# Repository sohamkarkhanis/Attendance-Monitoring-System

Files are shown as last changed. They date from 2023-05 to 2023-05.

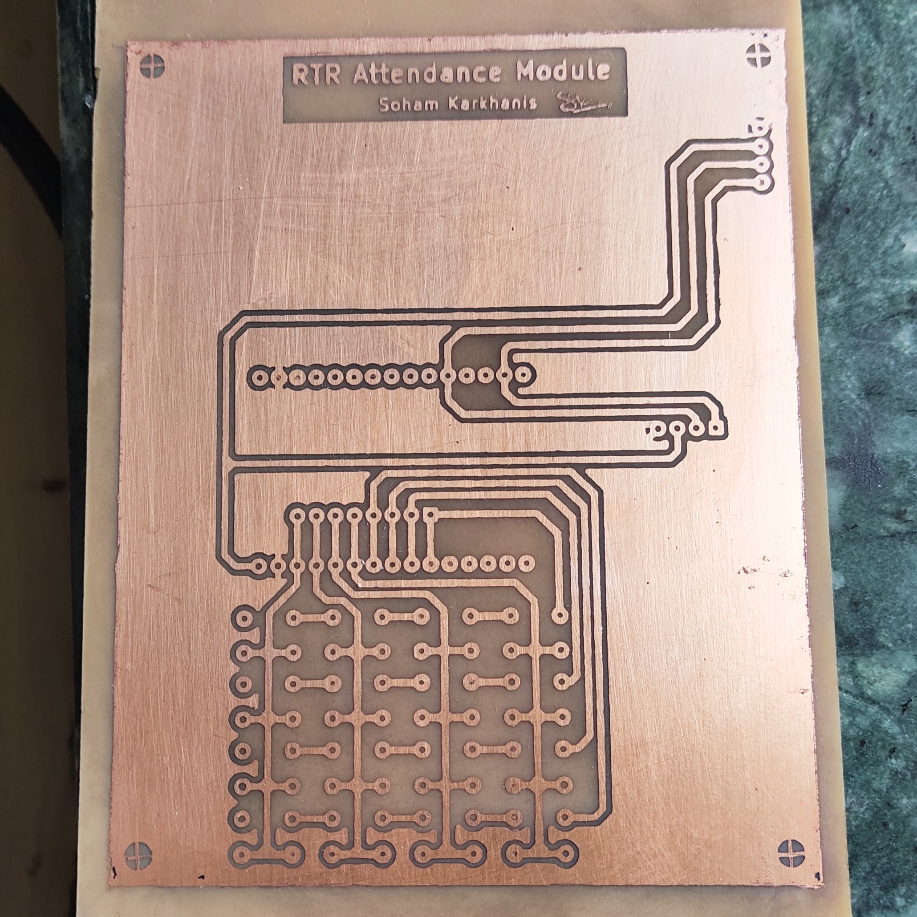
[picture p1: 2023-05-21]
PCB Design/Post Production Images/Manufactured PCB.jpg

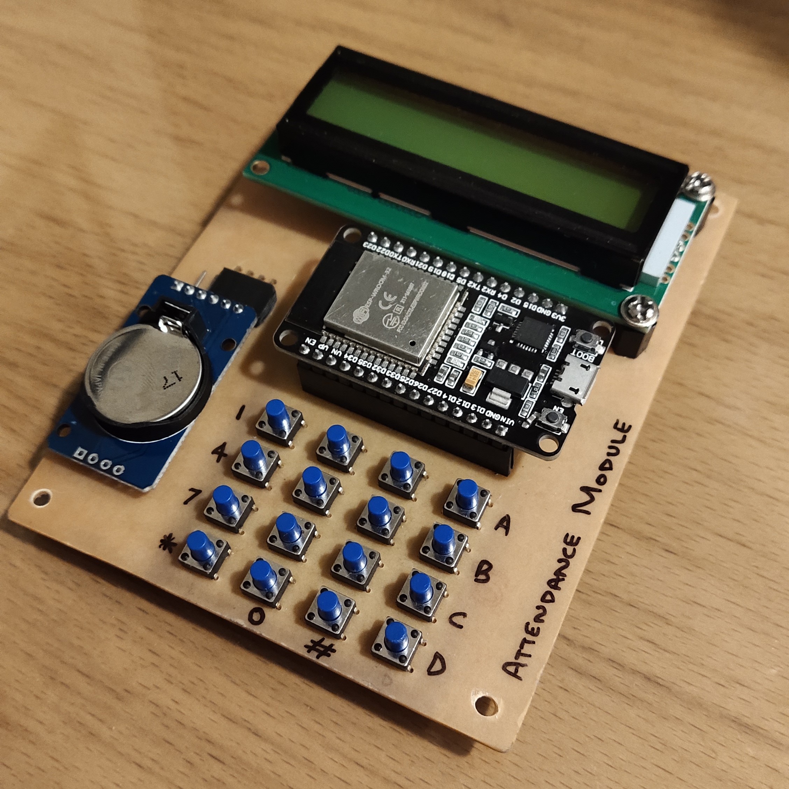
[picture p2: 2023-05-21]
PCB Design/Post Production Images/PCB Assembled.jpg

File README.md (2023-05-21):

# Attendance Monitoring System

This repository contains the code and documentation for an Attendance Monitoring System based on the ESP32 with a DS3231 RTC and the Hitachi HD44780, 16x2 character LCD with a PCF8574 I2C backpack. The system allows users to record attendance using a 4x4 matrix keypad through which Roll Numbers are entered and registered.

This project is designed to automate the process of attendance taking, saving time and reducing errors. With a focus on simplicity and cost-efficiency, it offers a dependable solution for monitoring the attendance in small institutions where advanced methods such as RFID, biometrics, etc… are not required.

Refer to the block diagram, PCB layout, schematic, and the code within the repository for detailed explanations and understanding of the project's functionality and hardware connections.

---

Author: Soham Karkhanis

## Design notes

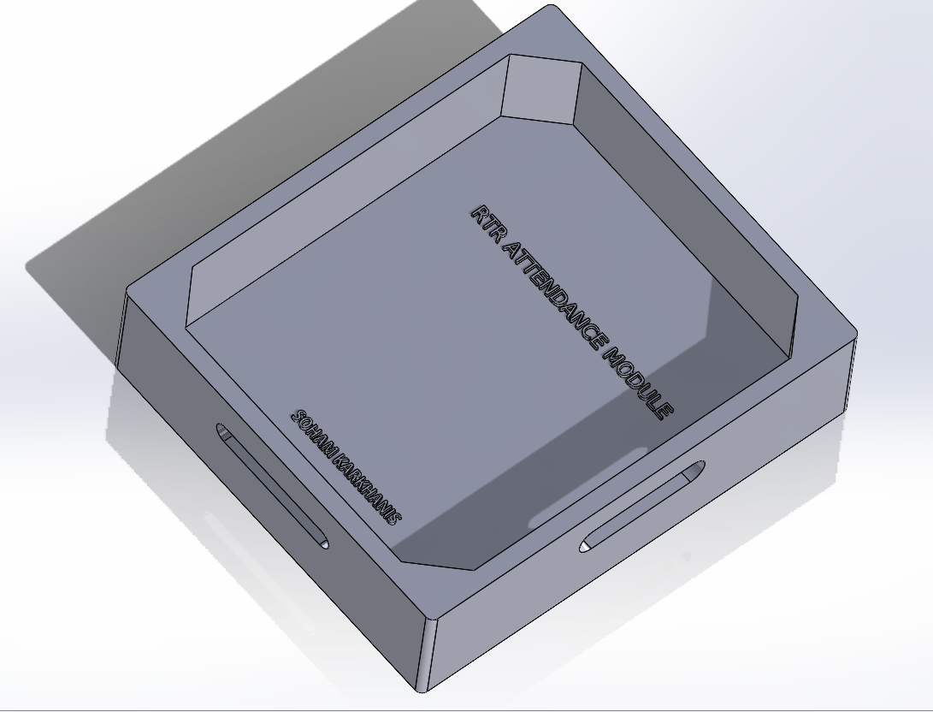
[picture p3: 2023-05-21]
Enclosure Design/Images/Box.png

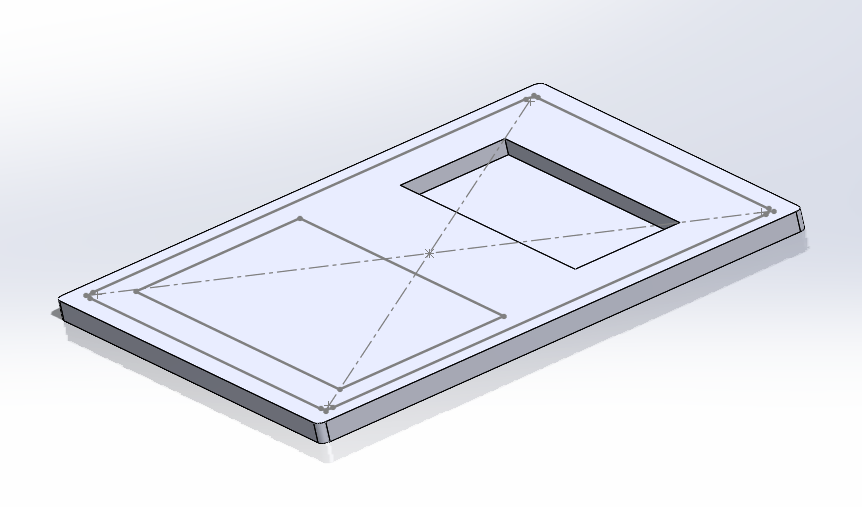
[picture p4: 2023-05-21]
Enclosure Design/Images/Lid.png

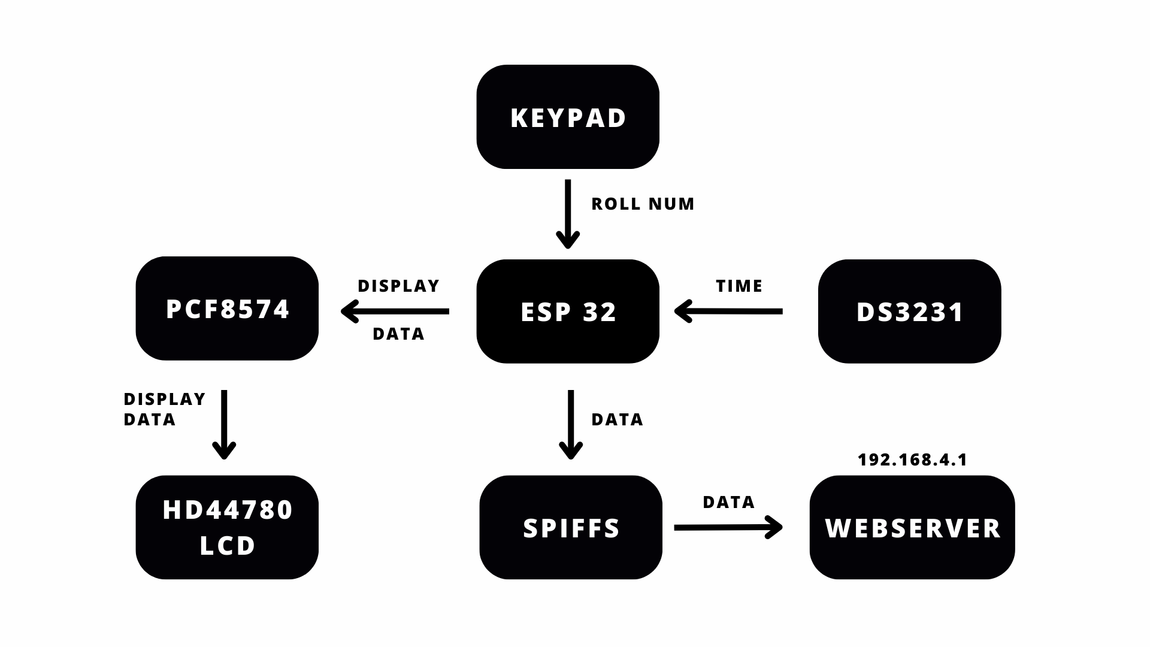
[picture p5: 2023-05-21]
Block Diagram.png

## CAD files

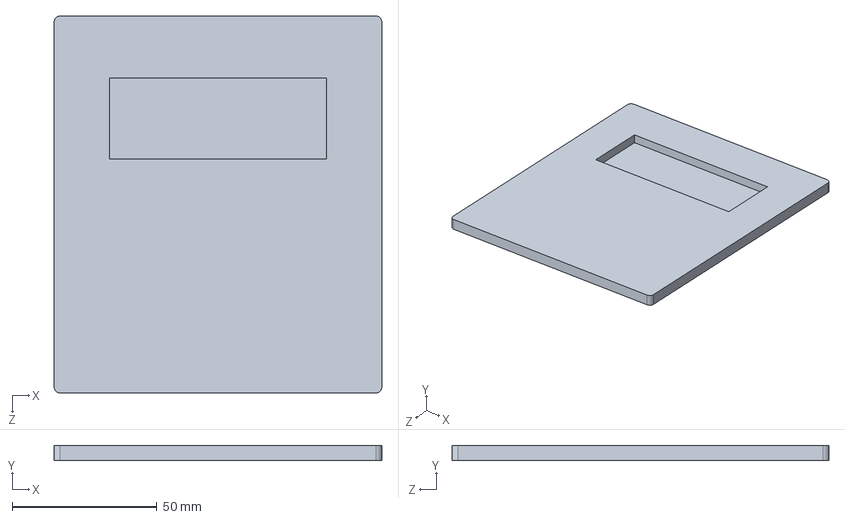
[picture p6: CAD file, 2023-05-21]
Enclosure Design/Lid.SLDPRT
113.0 x 5.00 x 130.0 mm

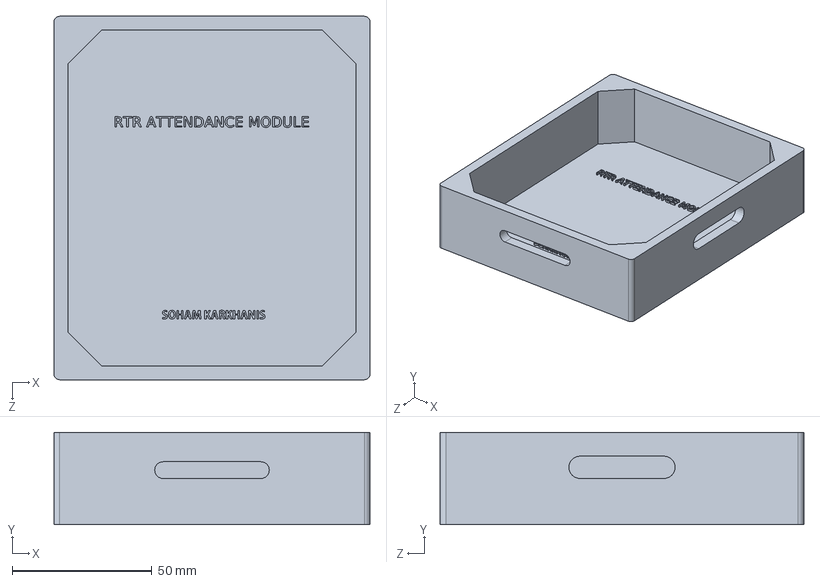
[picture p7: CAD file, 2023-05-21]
Enclosure Design/Box.SLDPRT
113.0 x 33.0 x 130.0 mm

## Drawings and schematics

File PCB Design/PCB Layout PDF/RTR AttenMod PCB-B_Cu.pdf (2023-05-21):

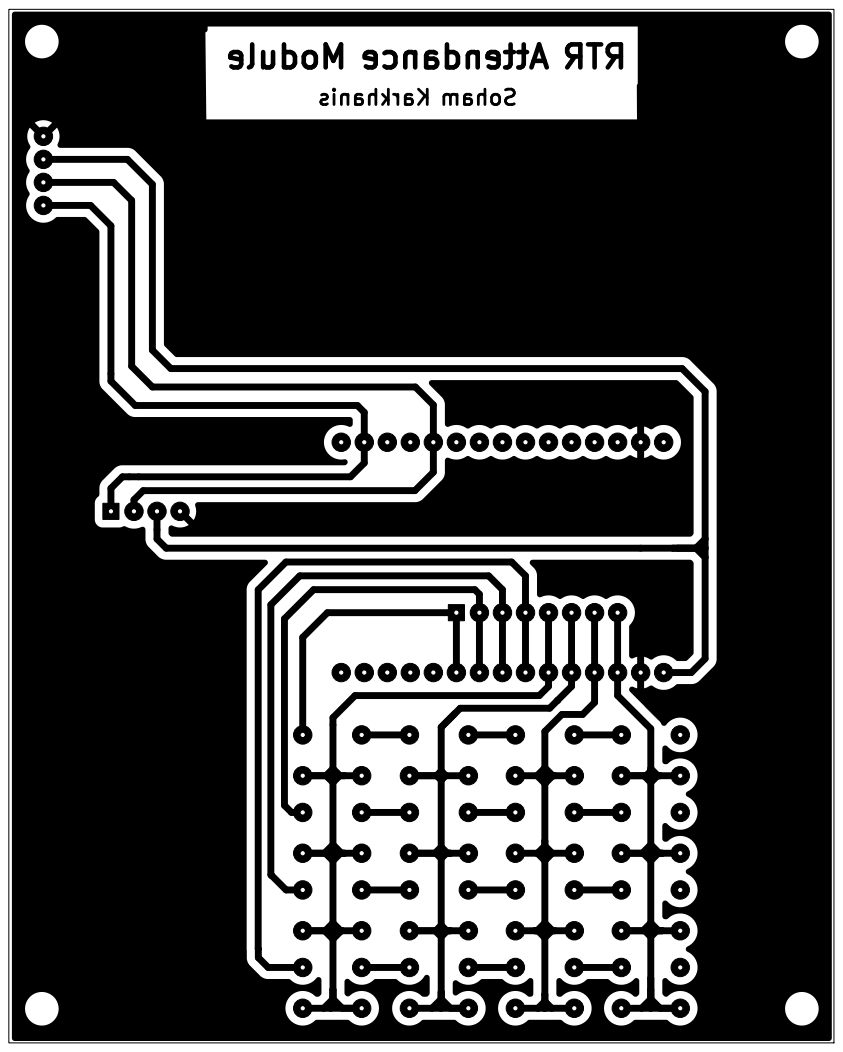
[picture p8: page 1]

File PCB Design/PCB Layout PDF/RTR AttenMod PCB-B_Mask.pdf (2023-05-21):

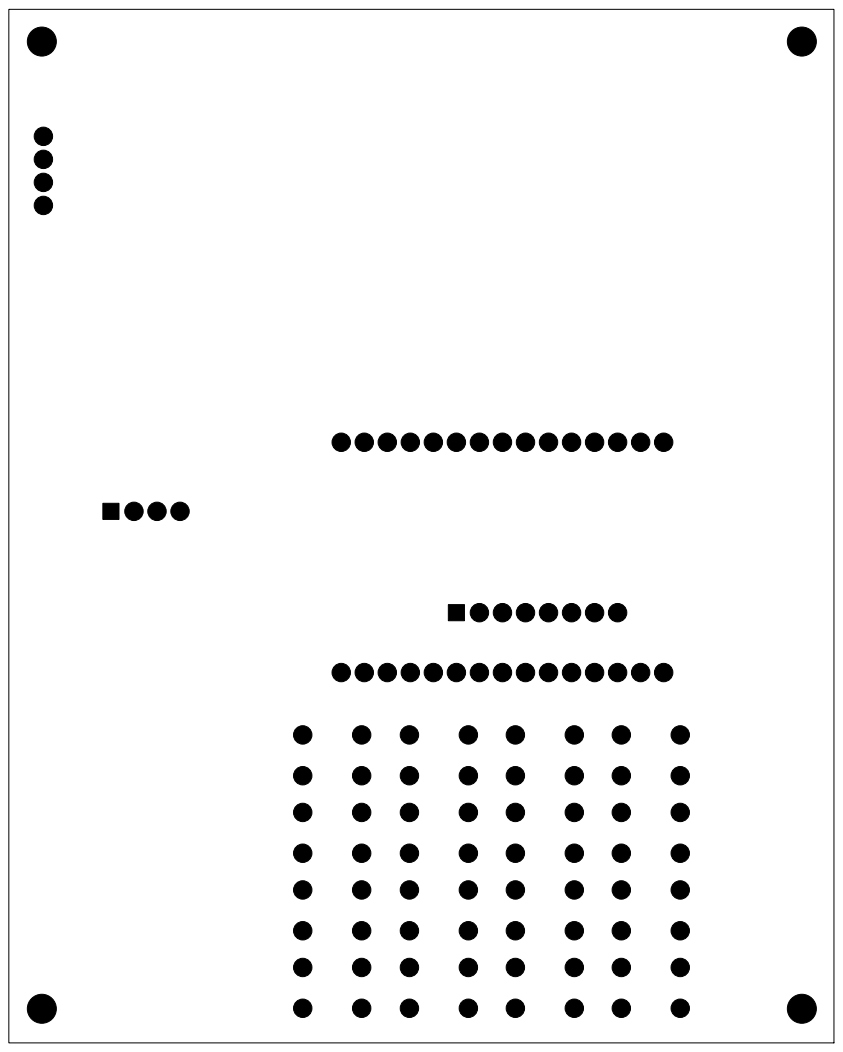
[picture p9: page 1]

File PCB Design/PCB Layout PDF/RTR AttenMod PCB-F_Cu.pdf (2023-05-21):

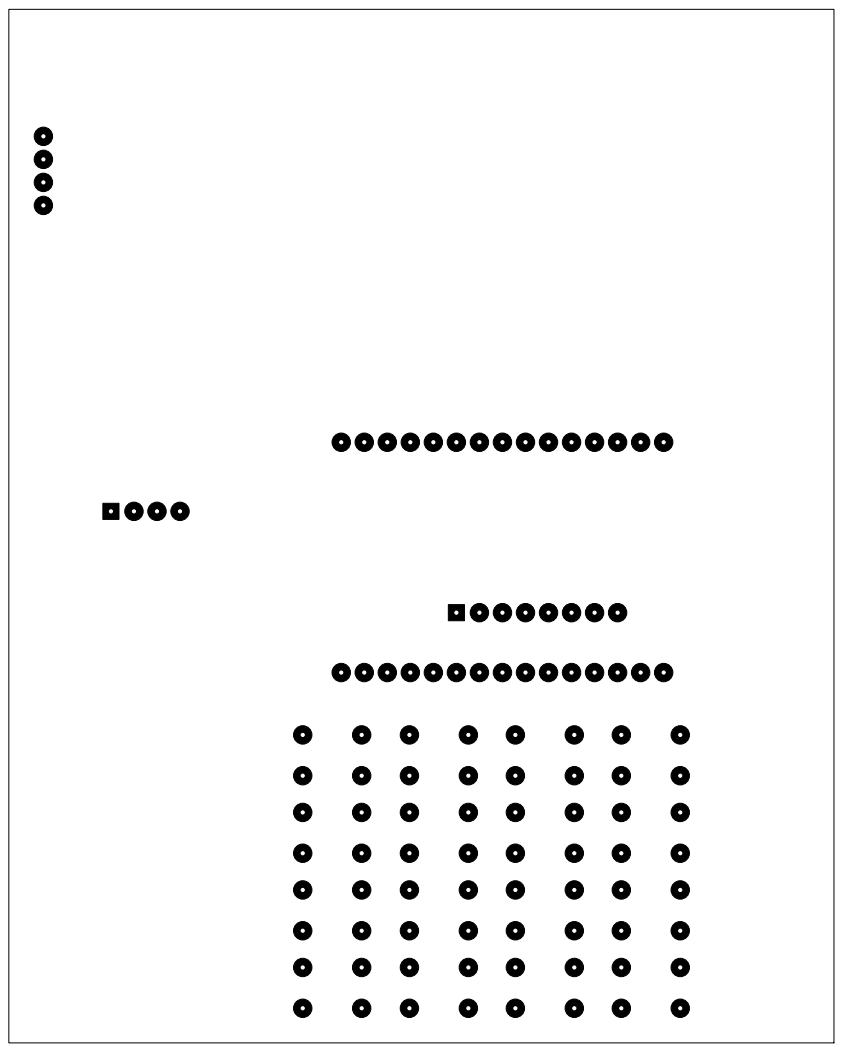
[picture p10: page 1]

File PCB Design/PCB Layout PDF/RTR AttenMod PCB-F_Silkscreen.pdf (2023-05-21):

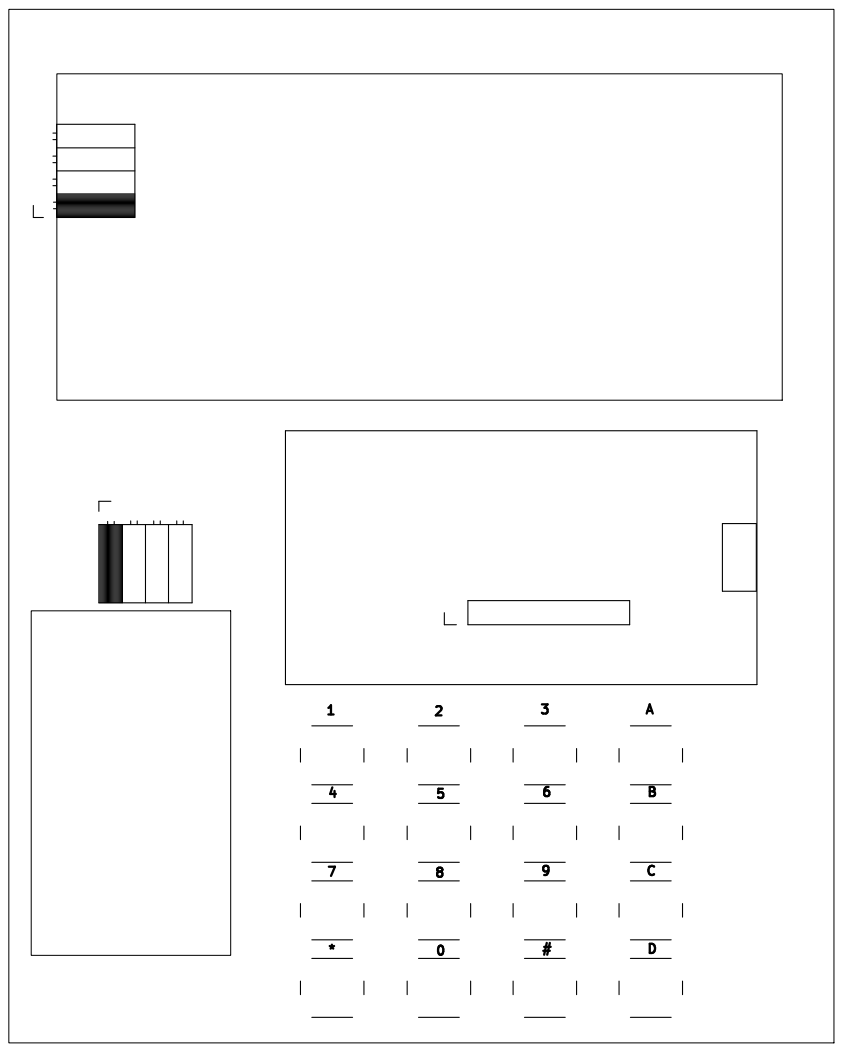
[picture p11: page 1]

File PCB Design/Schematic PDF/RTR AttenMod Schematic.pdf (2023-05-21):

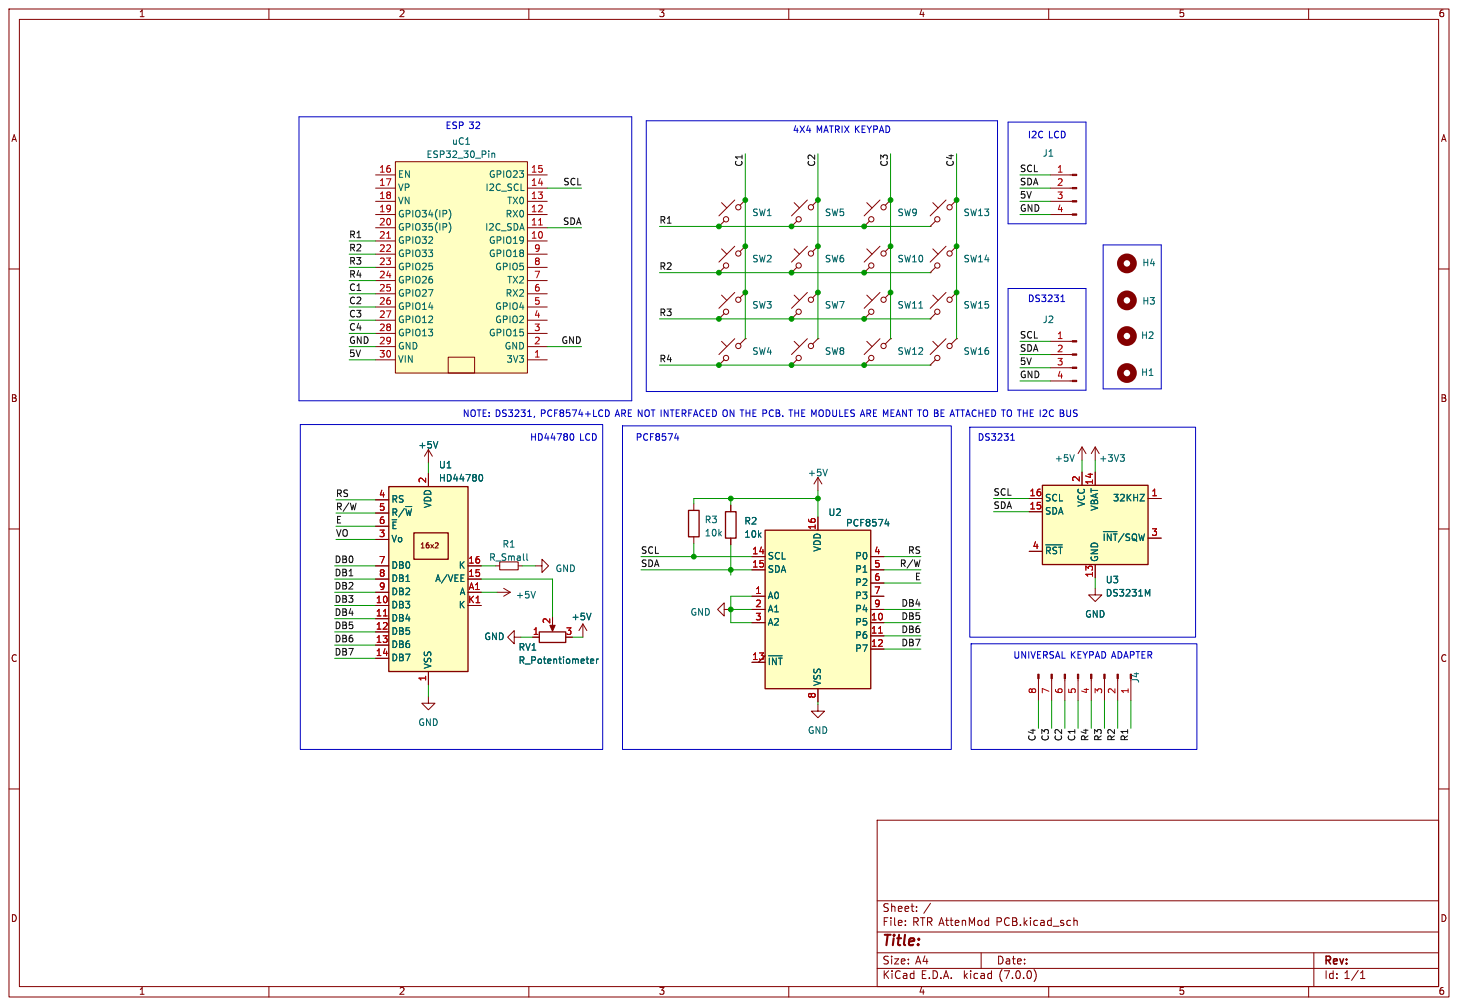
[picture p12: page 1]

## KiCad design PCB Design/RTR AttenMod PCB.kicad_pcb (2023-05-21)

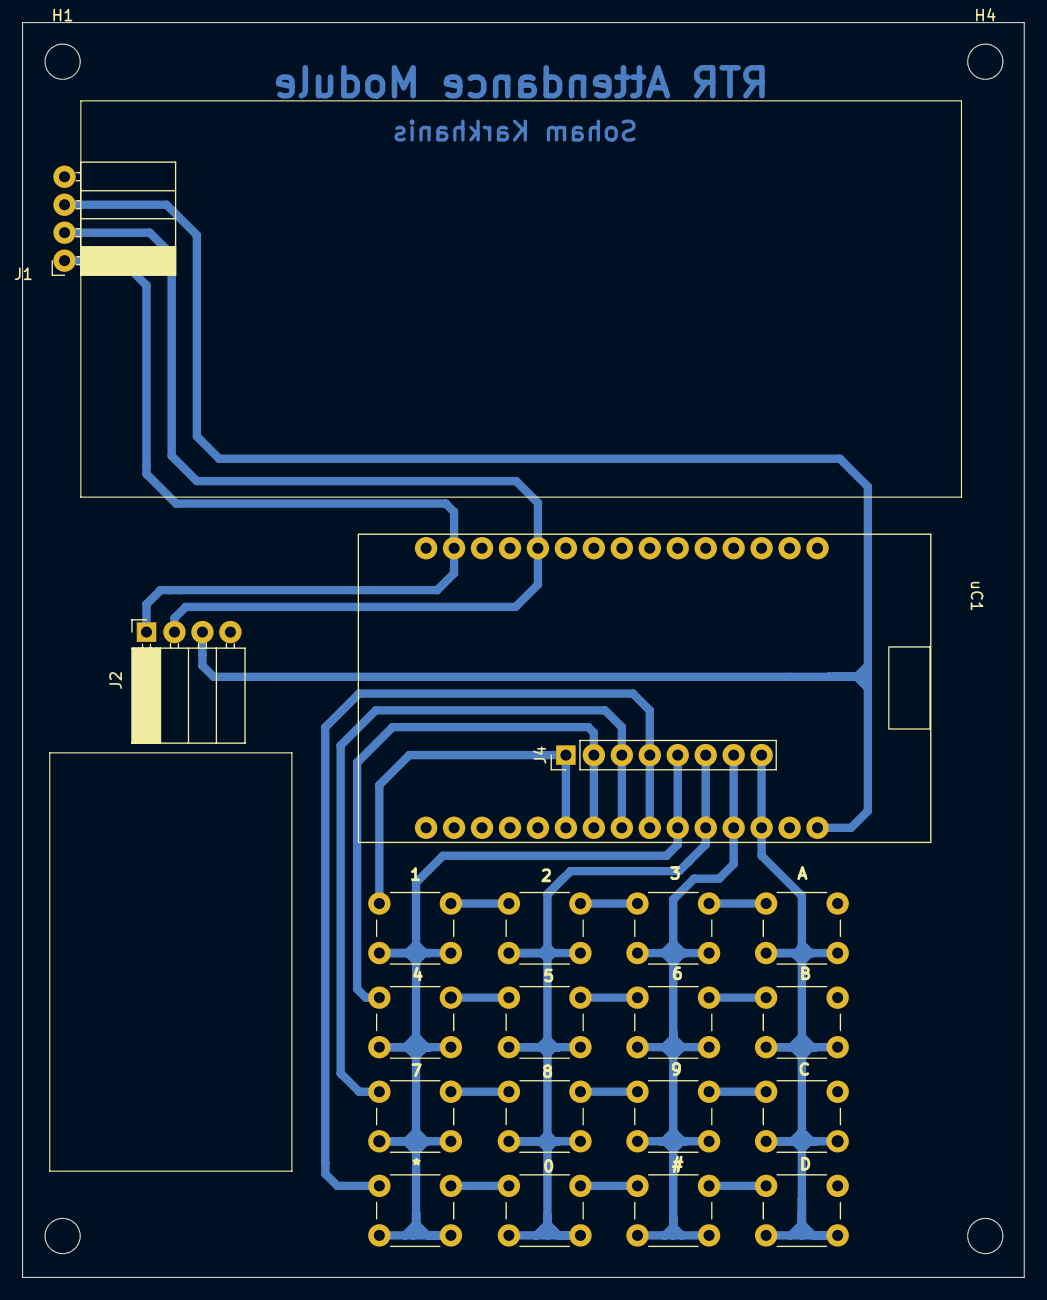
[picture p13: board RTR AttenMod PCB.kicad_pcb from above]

Board: 2 copper layers, 91.0 x 114.0 mm, 24 parts (0 on the bottom side), 12 nets.

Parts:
H1, H2, H3, H4: MountingHole; MountingHole_3.2mm_M3
J1, J2: Conn_01x04_Male; PinSocket_1x04_P2.54mm_Horizontal
J4: Conn_01x08_Pin; PinHeader_1x08_P2.54mm_Vertical
SW1, SW2, SW3, SW4, SW5, SW6, SW7, SW8, SW9, SW10, SW11, SW12, SW13, SW14, SW15, SW16: SW_Push_45deg; SW_PUSH_6mm
uC1: ESP32_30_Pin

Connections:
/5V: J1.3, J2.3, uC1.30 (VIN)
/C1: J4.5, SW1.2, SW2.2, SW3.2, SW4.2, uC1.25 (GPIO27)
/C2: J4.6, SW5.2, SW6.2, SW7.2, SW8.2, uC1.26 (GPIO14)
/C3: J4.7, SW9.2, SW10.2, SW11.2, SW12.2, uC1.27 (GPIO12)
/C4: J4.8, SW13.2, SW14.2, SW15.2, SW16.2, uC1.28 (GPIO13)
/R1: J4.1, SW1.1, SW5.1, SW9.1, SW13.1, uC1.21 (GPIO32)
/R2: J4.2, SW2.1, SW6.1, SW10.1, SW14.1, uC1.22 (GPIO33)
/R3: J4.3, SW3.1, SW7.1, SW11.1, SW15.1, uC1.23 (GPIO25)
/R4: J4.4, SW4.1, SW8.1, SW12.1, SW16.1, uC1.24 (GPIO26)
/SCL: J1.1, J2.1, uC1.14 (I2C SCL)
/SDA: J1.2, J2.2, uC1.11 (I2C SDA)
GND: J1.4, J2.4, uC1.2 (GND), uC1.29 (GND)

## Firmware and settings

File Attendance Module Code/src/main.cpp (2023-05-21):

/*
**************************************************************************************************
                                        Author: Soham Karkhanis
**************************************************************************************************

To better explain the code, here's a flowchart giving a brief overview of the attendance registering process,
skipping some of the finer details:

Start at home screen, automatically connect to Wifi if availiable
|
Read key from keypad
|
Is key '*'?
|
|--- Yes
|   |
|   Prompt for RollNumber input
|   |
|   Is RollNumber valid and mapped to a user?
|   |
|   |--- Yes
|   |   |
|   |   Confirm attendance
|   |   |
|   |   Is attendance confirmed?
|   |   |
|   |   |--- Yes
|   |   |   |
|   |   |   Display "Welcome" message
|   |   |   |
|   |   |   Mark attendance
|   |   |
|   |   |--- No
|   |   |   |
|   |   |   Back to homescreen
|   |
|   |--- No
|   |   |
|   |   Display error message: "User Not Found"
|   |
|   Clear LCD display
|
|--- No
|   |
|   Is key 'D'?
|   |
|   |--- Yes
|   |   |
|   |   Prompt for RollNumber input
|   |   |
|   |   Is RollNumber valid and mapped to a user?
|   |   |
|   |   |--- Yes
|   |   |   |
|   |   |   Confirm departure
|   |   |   |
|   |   |   Is departure confirmed?
|   |   |   |
|   |   |   |--- Yes
|   |   |   |   |
|   |   |   |   Display "Goodbye" message
|   |   |   |   |
|   |   |   |   Mark departure
|   |   |   |
|   |   |   |--- No
|   |   |   |   |
|   |   |   |   Back to homescreen
|   |   |
|   |   |--- No
|   |   |   |
|   |   |   Display error message: "User Not Found"
|   |
|   |
|   |
|   |--- No
|   |   |
|   |   |   Is key 'B'?
|   |   |   |
|   |   |   |--- Yes
|   |   |   |    |
|   |   |   |    Display IP Address
|   |   |   |--- No
|   |   |   |    |
|   |   |   |    Wait for keypress on homescreen

End

*/

#include "FS.h"
#include "SPIFFS.h"
#include "data.h"
#include <Arduino.h>
#include <ESPAsyncWebServer.h>
#include <Keypad.h>
#include <LiquidCrystal_I2C.h>
#include <WiFi.h>
#include <Wire.h>

// #define INIT_RTC

//----------------------------------------RTC---------------------------------------
#define DS3231_READ 0xD1
#define DS3231_WRITE 0xD0
#define DS3231_ADDR 0x68
#define DS3231_SECONDS 0x00
#define DS3231_MINUTES 0x01
#define DS3231_HOURS 0x02
#define DS3231_DAY 0x03
#define DS3231_DATE 0x04
#define DS3231_CEN_MONTH 0x05

#define DS3231_DEC_YEAR 0x06
#define DS3231_TEMP_MSB 0x11
#define DS3231_TEMP_LSB 0x12
const byte ROWS = 4;
const byte COLS = 4;
char keys[ROWS][COLS] = {
    { '1', '2', '3', 'A' },
    { '4', '5', '6', 'B' },
    { '7', '8', '9', 'C' },
    { '*', '0', '#', 'D' }
};

byte rowPins[ROWS] = { 32, 33, 25, 26 };        // connect to the row pinouts of the kpd
byte colPins[COLS] = { 27, 14, 12, 13 };        // connect to the column pinouts of the kpd
const char *ssid = "AttendanceModule";
const char *password = "password";

// Objects
AsyncWebServer server(80);
LiquidCrystal_I2C lcd(0x27, 16, 2);
byte klock[] = { 0x00, 0x0E, 0x15, 0x15, 0x1D, 0x11, 0x11, 0x0E };
Keypad keypad = Keypad(makeKeymap(keys), rowPins, colPins, ROWS, COLS);

char key;
uint8_t value = 0;
char const *wdays[] = { "Sun", "Mon", "Tue", "Wed", "Thu", "Fri", "Sat" };

uint8_t hours, minutes, seconds, datee, month, yearr, day;

String dataMessage;
float temp;
ulong timer_A;

// Function Prototypes
void getDate();
void getTime();
uint8_t toBcd(uint8_t num);
uint8_t fromBcd(uint8_t bcd);
uint8_t readRegister(uint8_t reg);
void writeRegister(uint8_t reg, uint8_t data);
void listDir(fs::FS &fs, const char *dirname, uint8_t levels);
void readFile(fs::FS &fs, const char *path);
void writeFile(fs::FS &fs, const char *path, const char *message);
void appendFile(fs::FS &fs, const char *path, const char *message);
void renameFile(fs::FS &fs, const char *path1, const char *path2);
void deleteFile(fs::FS &fs, const char *path);
void markAttendance(int rollNum, String name);
void markDeparture(int rollNum, String name);

// --------------------------------------------------------------------------------------- SETUP ----------
void setup() {
    Serial.begin(115200);
    Wire.begin();
    Serial.print("Setting AP (Access Point)…");
    WiFi.softAP(ssid, password);

    IPAddress IP = WiFi.softAPIP();
    Serial.print("AP IP address: ");
    Serial.println(IP);

    server.on("/", HTTP_GET, [](AsyncWebServerRequest *request) { request->send(SPIFFS, "/index.html", "text/html"); });
    server.on("/csv", HTTP_GET, [](AsyncWebServerRequest *request) { request->send(SPIFFS, "/RTR_Attendance.csv", "text/csv"); });
    // server.on("/plain", HTTP_GET, [](AsyncWebServerRequest *request) { request->send(200, "text/plain", "You have reached the WebServer for the RTR Attendance Module designed by Soham Karkhanis. \n Append /csv to the URL to get the csv file containing the attendance record"); });
    server.on("/test", HTTP_GET, [](AsyncWebServerRequest *request) { request->send_P(200, "text/plain", "Hello World"); });
    server.begin();

    if (!SPIFFS.begin(true)) {
        Serial.println("An Error has occurred while mounting SPIFFS");
        return;
    }

    File file = SPIFFS.open("/test.txt");
    if (!file) {
        Serial.println("Failed to open file for reading");
        return;
    }

    Serial.println("File Content:");
    while (file.available()) {
        Serial.print((char)file.read());
    }
    file.close();

#ifdef INIT_RTC
    writeRegister(DS3231_HOURS, 16);
    writeRegister(DS3231_MINUTES, 32);
    writeRegister(DS3231_SECONDS, 0);

    writeRegister(DS3231_DAY, 5);
    writeRegister(DS3231_DATE, 12);
    writeRegister(DS3231_CEN_MONTH, 5);
    writeRegister(DS3231_DEC_YEAR, 23);
#endif

    lcd.init();
    lcd.backlight();
    lcd.print("Initializing...");
    // lcd.createChar(0, klock);
    getDate();
    getTime();
    delay(800);
    lcd.clear();
    lcd.setCursor(0, 0);
    lcd.print(wdays[day]);
    lcd.print(" " + (String)datee + "/" + (String)month + "/" + (String)yearr);
    lcd.setCursor(0, 1);
    lcd.print("* Arr | D Depart");
    lcd.setCursor(0, 1);
    Serial.println(" ");
}
// --------------------------------------------------------------------------------------- SETUP END ----------
// ------------------------------------------------------------------------------------------------------------------------------ LOOP  ----------
void loop() {
    key = keypad.getKey();

    // --------------------------------------------------------------------------------------- IF KEY * DO ARRIVE STUFF  ----------
    if (key == '*') {
        lcd.clear();
        lcd.print("Enter Your RNum");
        lcd.setCursor(0, 1);
        key = ' ';
        while (key == NULL || key == ' ' || key == '*' || key == 'B' || key == 'D' || key == 'A') {
            key = keypad.getKey();
            if (key == 'B' || key == 'D' || key == 'A') {
                lcd.setCursor(0, 0);
                lcd.print("Enter Valid Num:");
            }
        }
        // ----------------------------------------------------------------------- C TO RETURN TO PREV MENU  ----------
        if (key == 'C') {
            getDate();
            getTime();
            lcd.clear();
            lcd.print(wdays[day]);
            lcd.print(" " + (String)datee + "/" + (String)month + "/" + (String)yearr);
            lcd.setCursor(0, 1);
            lcd.print("* Arr | D Depart");
            lcd.setCursor(0, 0);
            return;
        }

        lcd.setCursor(0, 1);
        lcd.print(key);
        value = (int)key - 48;
        value = value * 10;
        key = ' ';

        while (key == NULL || key == ' ' || key == '*' || key == 'B' || key == 'D' || key == 'A') {
            key = keypad.getKey();
            if (key == 'B' || key == 'D' || key == 'A') {
                lcd.setCursor(0, 0);
                lcd.print("Enter Valid Num:");
            }
        }

        if (key == 'C') {
            getDate();
            getTime();
            lcd.clear();
            lcd.print(wdays[day]);
            lcd.print(" " + (String)datee + "/" + (String)month + "/" + (String)yearr);
            lcd.setCursor(0, 0);
            lcd.print("* Arr | D Depart");
            lcd.setCursor(0, 1);

            return;
        }

        lcd.print(key);
        value = value + ((int)key - 48);
        lcd.setCursor(0, 0);
        lcd.print("# Confirm C Abrt");
        //  Serial.println("Press # to mark attendance or Press C to cancel");
        while (key != 'C' && key != '#')
            key = keypad.getKey();
        if (key == 'C') {
            getDate();
            getTime();
            lcd.clear();
            lcd.print(wdays[day]);
            lcd.print(" " + (String)datee + "/" + (String)month + "/" + (String)yearr);
            lcd.setCursor(0, 1);
            lcd.print("* Arr | D Depart");
            value = 0;
            // ----------------------------------------------------------------------- IF #, MARK ATTENDANCE  ----------
        } else if (key == '#') {
            getDate();
            getTime();
            if (student_data.find(value) == student_data.end()) {
                lcd.clear();
                lcd.setCursor(0, 0);
                lcd.print("Error");
                lcd.setCursor(0, 1);
                lcd.print("User Not Found");
                delay(2000);
            } else {
                auto student = student_data.find(value);
                markAttendance(value, student->second);
                lcd.clear();
                lcd.setCursor(0, 0);
                lcd.print("Welcome Back");
                lcd.setCursor(0, 1);
                lcd.print(student->second);
                delay(2000);
            }
            getDate();
            getTime();
            lcd.clear();
            lcd.print(wdays[day]);
            lcd.print(" " + (String)datee + "/" + (String)month + "/" + (String)yearr);
            lcd.setCursor(0, 1);
            lcd.print("* Arr | D Depart");
            lcd.setCursor(0, 0);
        }
        key = ' ';
    }
    // --------------------------------------------------------------------------------------- IF KEY D DO DEPART STUFF  ----------
    else if (key == 'D') {
        lcd.clear();
        lcd.print("Enter Your RNum");
        lcd.setCursor(0, 1);
        key = ' ';
        while (key == NULL || key == ' ' || key == '*' || key == 'B' || key == 'A' || key == 'D') {
            key = keypad.getKey();
            if (key == 'B' || key == '*' || key == 'A' || key == 'D') {
                lcd.setCursor(0, 0);
                lcd.print("Enter Valid Num:");
            }
        }
        if (key == 'C') {
            getDate();
            getTime();
            lcd.clear();
            lcd.print(wdays[day]);
            lcd.print(" " + (String)datee + "/" + (String)month + "/" + (String)yearr);
            lcd.setCursor(0, 1);
            lcd.print("* Arr | D Depart");
            lcd.setCursor(0, 0);
            value = 0;
            return;
        }
        lcd.setCursor(0, 1);
        lcd.print(key);
        value = (int)key - 48;
        value = value * 10;
        key = ' ';
        while (key == NULL || key == ' ' || key == '*' || key == 'B' || key == '*' || key == 'A') {
            key = keypad.getKey();
            if (key == 'B' || key == '*' || key == 'A') {
                lcd.setCursor(0, 0);
                lcd.print("Enter Valid Num:");
            }
        }
        if (key == 'C') {
            getDate();
            getTime();
            lcd.clear();
            lcd.print(wdays[day]);
            lcd.print(" " + (String)datee + "/" + (String)month + "/" + (String)yearr);
            lcd.setCursor(0, 1);
            lcd.print("* Arr | D Depart");
            lcd.setCursor(0, 0);
            value = 0;
            return;
        }
        lcd.print(key);
        value = value + ((int)key - 48);
        lcd.setCursor(0, 0);
        lcd.print("# Confirm C Abrt");
        // Serial.println("Press # to mark attendance or Press C to cancel");
        while (key != 'C' && key != '#')
            key = keypad.getKey();
        if (key == 'C') {
            getDate();
            getTime();
            lcd.clear();
            lcd.print(wdays[day]);
            lcd.print(" " + (String)datee + "/" + (String)month + "/" + (String)yearr);
            lcd.setCursor(0, 1);
            lcd.print("* Arr | D Depart");
            lcd.setCursor(0, 0);
            value = 0;
        } else if (key == '#') {
            getDate();
            getTime();
            if (student_data.find(value) == student_data.end()) {
                lcd.clear();
                lcd.setCursor(0, 0);
                lcd.print("Error");
                lcd.setCursor(0, 1);
                lcd.print("User Not Found");
                delay(2000);
            } else {
                auto student = student_data.find(value);
                markDeparture(value, student->second);
                lcd.clear();
                lcd.setCursor(0, 0);
                lcd.print("See You Soon");
                lcd.setCursor(0, 1);
                lcd.print(student->second);
                delay(2000);
            }

            getDate();
            getTime();
            lcd.clear();
            lcd.print(wdays[day]);
            lcd.print(" " + (String)datee + "/" + (String)month + "/" + (String)yearr);
            lcd.setCursor(0, 1);
            lcd.print("* Arr | D Depart");
            lcd.setCursor(0, 0);
        }
        key = ' ';
    }
    // --------------------------------------------------------------------------------------- IF KEY B PRINT IP, DATE   ----------
    if (key == 'B') {
        lcd.clear();
        lcd.setCursor(0, 0);
        lcd.print(WiFi.softAPIP());
        delay(2000);
        lcd.clear();
        lcd.print(wdays[day]);
        lcd.print(" " + (String)datee + "/" + (String)month + "/" + (String)yearr);
        lcd.setCursor(0, 1);
        lcd.print("* Arr | D Depart");
        lcd.setCursor(0, 0);
    }
}
// ------------------------------------------------------------------------------------------------------------------------------ LOOP END  ----------

//----------------------------------------RTC FUNCTIONS---------------------------------------

// Reads the current date from the RTC module and stores it in variables
void getDate() {
    day = readRegister(DS3231_DAY);
    hours = readRegister(DS3231_HOURS);
    minutes = readRegister(DS3231_MINUTES);
    seconds = readRegister(DS3231_SECONDS);
    datee = readRegister(DS3231_DATE);
    month = readRegister(DS3231_CEN_MONTH);
    yearr = readRegister(DS3231_DEC_YEAR);
    temp = ((readRegister(DS3231_TEMP_MSB) << 8 | readRegister(DS3231_TEMP_LSB)) >> 6) / 4.0f;
}

// Reads the current time from the RTC module and stores it in variables
void getTime() {
    hours = readRegister(DS3231_HOURS);
    minutes = readRegister(DS3231_MINUTES);
    seconds = readRegister(DS3231_SECONDS);
    yearr = readRegister(DS3231_DEC_YEAR);
    temp = ((readRegister(DS3231_TEMP_MSB) << 8 | readRegister(DS3231_TEMP_LSB)) >> 6) / 4.0f;
}

// Converts a decimal number to Binary Coded Decimal (BCD) format
uint8_t toBcd(uint8_t num) {
    uint8_t bcd = ((num / 10) << 4) + (num % 10);
    return bcd;
}

// Converts a BCD number to decimal format
uint8_t fromBcd(uint8_t bcd) {
    uint8_t num = (10 * ((bcd & 0xf0) >> 4)) + (bcd & 0x0f);
    return num;
}

// Reads a specific register from the RTC module using the Wire library
uint8_t readRegister(uint8_t reg) {
    Wire.beginTransmission(DS3231_ADDR);
    Wire.write(reg);
    Wire.endTransmission();
    Wire.requestFrom(DS3231_ADDR, 1);
    return fromBcd(Wire.read());
}

// Writes data to a specific register of the RTC module using the Wire library
void writeRegister(uint8_t reg, uint8_t data) {
    Wire.beginTransmission(DS3231_ADDR);
    Wire.write(reg);
    Wire.write(toBcd(data));
    Wire.endTransmission();
}

//----------------------------------------RTC FUNCTIONS END---------------------------------------

//----------------------------------------ATTENDANCE FUNCTIONS------------------------------------
// Marks the attendance by creating a data message with the current date, time, roll number, name, and "Arrival" status. The message is then printed and appended to a CSV file.
void markAttendance(int rollNum, String name) {
    dataMessage = (String)datee + "/" + (String)month + "/" + (String)yearr + "," + (String)hours + ":" + (String)minutes + ":" + (String)seconds + "," + (String)rollNum + "," + (String)name + "," + "Arrival" + "\n";

    Serial.print("Attendance Marked: ");
    Serial.println(dataMessage);
    appendFile(SPIFFS, "/RTR_Attendance.csv", dataMessage.c_str());
}

// Marks the departure by creating a data message with the current date, time, roll number, name, and "Departure" status. The message is then printed and appended to a CSV file.
void markDeparture(int rollNum, String name) {
    dataMessage = (String)datee + "/" + (String)month + "/" + (String)yearr + "," + (String)hours + ":" + (String)minutes + ":" + (String)seconds + "," + (String)rollNum + "," + (String)name + "," + "Departure" + "\n";

    Serial.print("Attendance Marked: ");
    Serial.println(dataMessage);
    appendFile(SPIFFS, "/RTR_Attendance.csv", dataMessage.c_str());
}

// --------------------------------------------------------------------------------- SPIFFS CMDS -----------------------------------------
// Lists the contents of a directory in the SPIFFS file system recursively.
void listDir(fs::FS &fs, const char *dirname, uint8_t levels) {
    Serial.printf("Listing directory: %s\r\n", dirname);

    File root = fs.open(dirname);
    if (!root) {
        Serial.println("− failed to open directory");
        return;
    }
    if (!root.isDirectory()) {
        Serial.println(" − not a directory");
        return;
    }

    File file = root.openNextFile();
    while (file) {
        if (file.isDirectory()) {
            Serial.print("  DIR : ");
            Serial.println(file.name());
            if (levels) {
                listDir(fs, file.name(), levels - 1);
            }
        } else {
            Serial.print("  FILE: ");
            Serial.print(file.name());
            Serial.print("\tSIZE: ");
            Serial.println(file.size());
        }
        file = root.openNextFile();
    }
}

// Reads the content of a file from the SPIFFS file system
void readFile(fs::FS &fs, const char *path) {
    Serial.printf("Reading file: %s\r\n", path);

    File file = fs.open(path);
    if (!file || file.isDirectory()) {
        Serial.println("− failed to open file for reading");
        return;
    }

    Serial.println("− read from file:");
    while (file.available()) {
        Serial.write(file.read());
    }
}

void writeFile(fs::FS &fs, const char *path, const char *message) {
    Serial.printf("Writing file: %s\r\n", path);

    File file = fs.open(path, FILE_WRITE);
    if (!file) {
        Serial.println("− failed to open file for writing");
        return;
    }
    if (file.print(message)) {
        Serial.println("− file written");
    } else {
        Serial.println("− frite failed");
    }
}

void appendFile(fs::FS &fs, const char *path, const char *message) {
    Serial.printf("Appending to file: %s\r\n", path);

    File file = fs.open(path, FILE_APPEND);
    if (!file) {
        Serial.println("− failed to open file for appending");
        return;
    }
    if (file.print(message)) {
        Serial.println("− message appended");
    } else {
        Serial.println("− append failed");
    }
}

void renameFile(fs::FS &fs, const char *path1, const char *path2) {
    Serial.printf("Renaming file %s to %s\r\n", path1, path2);
    if (fs.rename(path1, path2)) {
        Serial.println("− file renamed");
    } else {
        Serial.println("− rename failed");
    }
}

void deleteFile(fs::FS &fs, const char *path) {
    Serial.printf("Deleting file: %s\r\n", path);
    if (fs.remove(path)) {
        Serial.println("− file deleted");
    } else {
        Serial.println("− delete failed");
    }
}
